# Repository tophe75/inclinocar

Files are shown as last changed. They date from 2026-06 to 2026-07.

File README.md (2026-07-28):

# InclinoCar

Rooftop tent leveling assistant. Runs on three hardware targets (ESP32-C3 + MPU-6050, M5StickC Plus, or M5StickS3), displays real-time pitch and roll on-device, and connects to the InclinoCar Android app via Bluetooth.

## Web Installer

Flash firmware directly in your browser — no drivers or software needed.

> ⚠️ Flash the device **before** assembling it into the case — the original case has no access hole for the BOOT button once assembled.

👉 **[tophe75.github.io/inclinocar](https://tophe75.github.io/inclinocar/)**

Requires Chrome or Edge on desktop.

---

## Latest Releases

🔧 **Firmware:**
- ESP32-C3 Super Mini 
- M5StickC Plus 
- M5StickS3 

🤖 **Android:** 

🍎 **iOS:** 

---

## Hardware

InclinoCar runs on three hardware targets. The ESP32-C3 is the DIY option; the two M5Stack sticks are all-in-one units with built-in display, IMU, and battery.

### Option 1 — ESP32-C3 Super Mini (DIY)

- [ESP32-C3 Super Mini](https://www.amazon.com/DWEII-ESP32-C3-Development-Supermini-Bluetooth/dp/B0G5XS345R)
- [SSD1306 OLED display 128×64 (I2C)](https://www.amazon.com/UCTRONICS-SSD1306-Self-Luminous-Display-Raspberry/dp/B072Q2X2LL)
- [MPU-6050 GY-521 accelerometer/gyroscope](https://www.amazon.com/EPLZON-MPU-6050-Accelerometer-Gyroscope-Converter/dp/B09TVYVC6X)
- [Momentary push button](https://www.amazon.com/Gebildet-Momentary-Button-Switch-Railway/dp/B07YDHP3HS)
- [Jumper wires (26 AWG Silicone)](https://www.amazon.com/Fermerry-Stranded-Colors-Flexible-electrical/dp/B089D3T1JD)

### Option 2 — M5StickC Plus

All-in-one unit with built-in MPU6886 IMU, colour display and battery. No wiring needed. The MPU6886 can drift and is a little noisy — acceptable for leveling but not the best of the three.

[M5StickC Plus](https://shop.m5stack.com/products/m5stickc-plus-esp32-pico-mini-iot-development-kit)

### Option 3 — M5StickS3 (recommended all-in-one)

All-in-one unit with the newer BMI270 IMU — noticeably more stable than the MPU6886 — plus a larger 250mAh battery.

[M5StickS3](https://shop.m5stack.com/products/m5sticks3-esp32s3-mini-iot-dev-kit)

> ℹ️ The M5StickS3 can **freeze (not reboot)** when connected to a PC via USB with no application actively reading the serial port — e.g. developing with VS Code/PlatformIO open but no serial monitor attached. It stays frozen on whatever it last displayed; opening a serial monitor un-freezes it immediately, closing the monitor again re-freezes it. This only affects that specific dev-workflow scenario — it does not happen through the [Web Installer](https://tophe75.github.io/inclinocar/) (its console actively reads the output), and normal use (battery, USB charger, power bank, car USB, or connected only to the phone app) is unaffected.

### Wiring (ESP32-C3 only)

All devices share the same I2C bus on GPIO6 and GPIO7.

```
ESP32-C3          SSD1306 OLED
─────────         ────────────
3.3V      →       VCC
GND       →       GND
GPIO6     →       SDA
GPIO7     →       SCL

ESP32-C3          MPU-6050 GY-521
─────────         ───────────────
3.3V      →       VCC
GND       →       GND
GPIO6     →       SDA
GPIO7     →       SCL
GND       →       AD0        (sets I2C address to 0x68)

ESP32-C3          Button
─────────         ──────
GPIO5     →       Terminal 1
GND       →       Terminal 2
(internal pull-up — no resistor needed)
```

The M5StickC Plus and M5StickS3 need no wiring — display, IMU, button and battery are all built in.

---

## Installation

1. Open the [Web Installer](https://tophe75.github.io/inclinocar/) in Chrome or Edge
2. Select your hardware (ESP32-C3, M5StickC Plus, or M5StickS3)
3. Select the firmware version
4. Click **Install**
5. Select **Erase device** when prompted — required for first install
6. Device reboots automatically when done

For the M5 sticks, hold the power button ~2 seconds to enter download mode if the installer can't connect.

---

## Usage

### Boot Screen

On power-up the device shows the device nickname, firmware version, MAC address and PIN for 5 seconds:

```
  InclinoCore
  v26.07.2
  E8:3D:C1:9E:43:38
  PIN: 9208
  Cal loaded
```

You can redisplay this screen at any time for 10 seconds — handy for reading the pairing PIN without power-cycling the device (see **Button** below).

### Display

```
  InclinoCore        PIN:9208
  ──────────────────────────
  P  +2.3°
  R  -1.1°
  ──────────────────────────
  Adjust...            ← or ** LEVEL ** when within 1°
```

`BT` appears in the top right when the app is connected. The M5 sticks also show battery percentage.

### Button

| Action | Function |
|---|---|
| Short press | Cycle display brightness (25% → 50% → 75% → 100% → 25%) |
| Hold 1 second | Calibrate (keep device still on flat ground) |
| Show boot screen for 10s | Redisplay nickname, MAC, and PIN — see device-specific gesture below |

- **ESP32-C3**: the wired push button. Short press / hold 1s as above. **Double-press** (two clicks within 350ms) shows the boot screen — this adds a ~350ms delay before short-press brightness cycling fires, needed to tell a single click from the first half of a double-click.
- **M5StickC Plus / M5StickS3**: `BtnA`, the front button (same side as the display — labeled **M5** on the M5StickC Plus; unlabeled but colored blue on the M5StickS3), for short press / hold 1s as above. `BtnB`, the top button, shows the boot screen with a single press. The bottom power button is unrelated to these functions.

Default brightness on first boot is 25%.

### Calibration

Hold the button (`BtnA` on the M5 sticks) for 1 second with the vehicle on flat level ground. The device takes 50 readings and saves the offsets to flash — they survive reboots and firmware updates.

### Bluetooth Pairing

1. Open the InclinoCar app
2. Tap the **⋮** menu → **Scan for InclinoCore**
3. Select your device from the list (identified by MAC address)
4. Enter the 4-digit PIN shown on the device display
5. The app remembers your device and auto-connects next time

The PIN is unique to each device and never changes.

### Bluetooth Data

The device sends JSON over Nordic UART Service (NUS) every 100ms:

```json
{"p":1.2,"r":0.3,"n":"InclinoCore"}
```

`p` = pitch (degrees), `r` = roll (degrees), `n` = device nickname

---

## Troubleshooting

| Problem | Solution |
|---|---|
| Display blank after flash (ESP32-C3) | Check SDA=GPIO6, SCL=GPIO7, VCC=3.3V |
| IMU not found (ESP32-C3) | Check MPU-6050 wiring, AD0 must be GND |
| M5 stick won't flash | Hold power button ~2s to enter download mode |
| M5StickS3 freezes when connected to PC (VS Code open, no serial monitor) | Normal — open a serial monitor to un-freeze it, or run on battery/charger/power bank instead. Only affects USB dev workflows, not normal use or the Web Installer. |
| Values drifting | Hold button 1s to calibrate |
| App can't find device | Menu → Scan for InclinoCore, check device is powered on |
| Wrong PIN | Check the device display — PIN is shown on boot screen and top-right when not connected |
| Web installer fails | Hard refresh (Ctrl+Shift+R) or use incognito window |
| NVS errors in serial log | Flash with Erase device selected in web installer |

---

## Android App

Download the latest `InclinoCar-installer.apk` from [GitHub Releases](https://github.com/tophe75/inclinocar/releases).

**Install instructions:**
1. Download the APK on your Android phone
2. Settings → Security → Install unknown apps → allow your browser
3. Open the APK and tap Install

**Features:**
- Auto-connects to last known device on startup
- PIN-based pairing for identifying your device among multiple units
- Bubble level with car silhouette and directional arrows
- Pitch and roll readout with colour coding (green < 1°, amber < 3°, red ≥ 3°)
- Calibrate remotely from the app
- Set a custom nickname for your device
- Known devices list with ability to remove saved devices
- Screen-on mode to keep display active while leveling

---

## 3D Printed Parts

STL files for cases and mounting brackets are in the `3d-print/` folder. Print in PETG or ABS — avoid PLA as it can warp in a hot car.

---

## Project Structure

```
firmware/
  firmware-esp32c3/   PlatformIO project (ESP32-C3 + MPU-6050 + SSD1306)
  firmware-m5stick/   PlatformIO project (M5StickC Plus)
  firmware-m5sticks3/ PlatformIO project (M5StickS3)
app/                  Flutter app (Android + iOS)
  app/lib/            Dart source code
  app/android/        Android build files and icons
  app/ios/            iOS build files and icons
  app/assets/         App assets (master icon, Play Store icon)
docs/                 GitHub Pages web installer
3d-print/             STL files for cases and mounting brackets
scripts/              Build utilities (version injection)
.github/workflows/    CI/CD pipelines
```

## Building Locally

**Firmware** — requires [VS Code](https://code.visualstudio.com/) and [PlatformIO](https://platformio.org/install/ide?install=vscode).
Open the relevant `firmware/firmware-*` folder in VS Code and click **Upload**.

**App** — requires [Flutter](https://flutter.dev/docs/get-started/install) SDK.
```bash
cd app
flutter pub get
flutter build apk --release
```

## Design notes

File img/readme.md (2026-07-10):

inclinocar_andriod_app_screenshoot

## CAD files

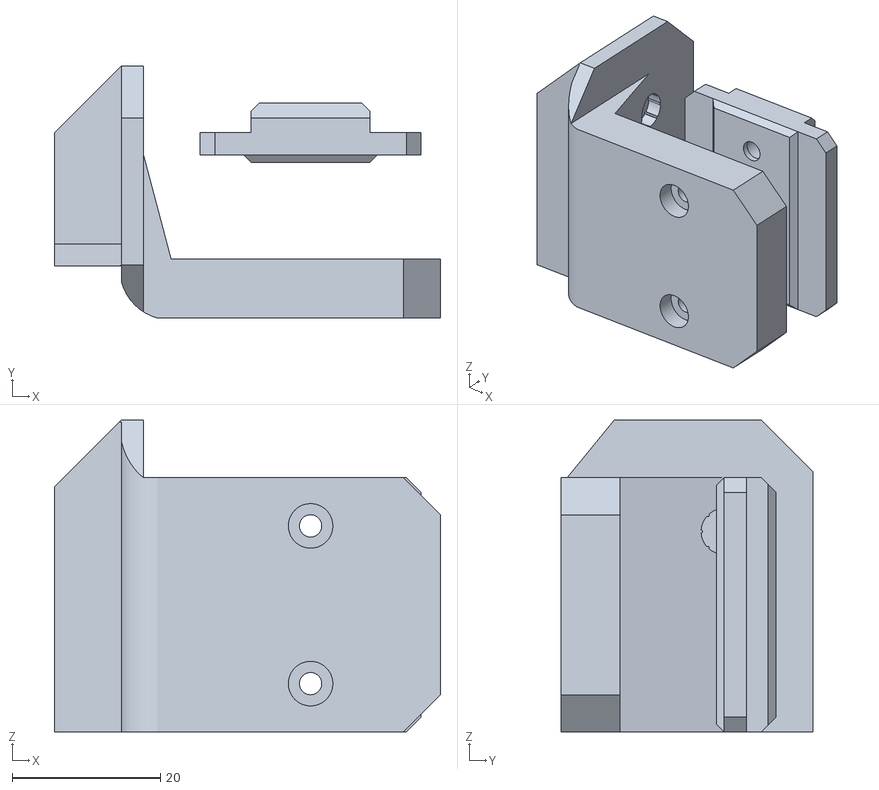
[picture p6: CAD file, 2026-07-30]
3d-print/brackets/Taktältarna_Åreskutan_2.0/InclinoCar M5S3 v26.07.1 - Bracket_TT_Åreskutan2.0.stl
52.0 x 34.0 x 42.0

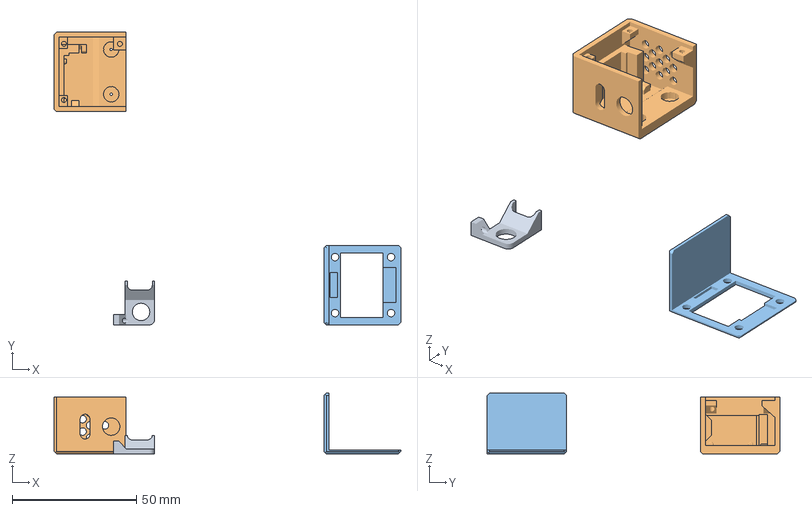
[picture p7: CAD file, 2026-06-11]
3d-print/core/esp32-c3_supermini/InclinoCar Core Case.3mf
139.5 x 117.7 x 24.5 mm
InclinoCar Core Case v26.1.0 - Clip.stl
InclinoCar Core Case v26.1.0 - Box.stl
InclinoCar Core Case v26.1.0 - Lid.stl

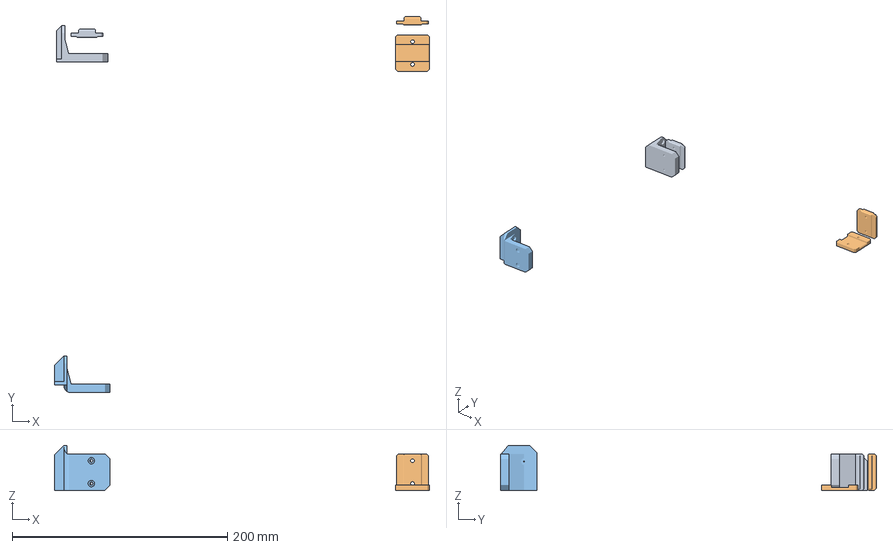
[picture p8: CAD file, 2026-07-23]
3d-print/brackets/Taktältarna_Åreskutan_2.0/InclinoCar - TT Brackets.3mf
349.2 x 349.7 x 42.0 mm
InclinoCar Core Case v26.1.0 - Bracket_TT_Åreskutan2.0.stl
InclinoCar Core Case v26.1.0 - Powerbank_TT_Åreskutan2.0.stl
InclinoCar M5S3 v26.07.1 - Bracket_TT_Åreskutan2.0.stl

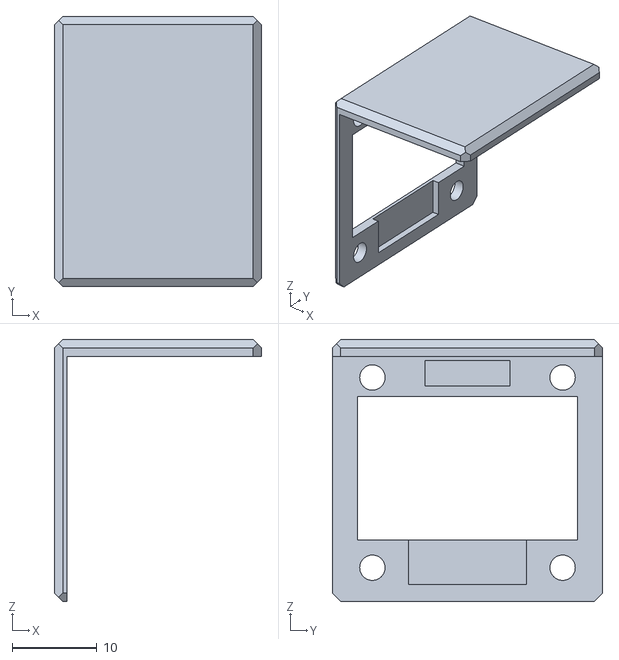
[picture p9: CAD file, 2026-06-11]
3d-print/core/esp32-c3_supermini/InclinoCar Core Case v26.1.0 - Lid.stl
24.5 x 32.0 x 31.0

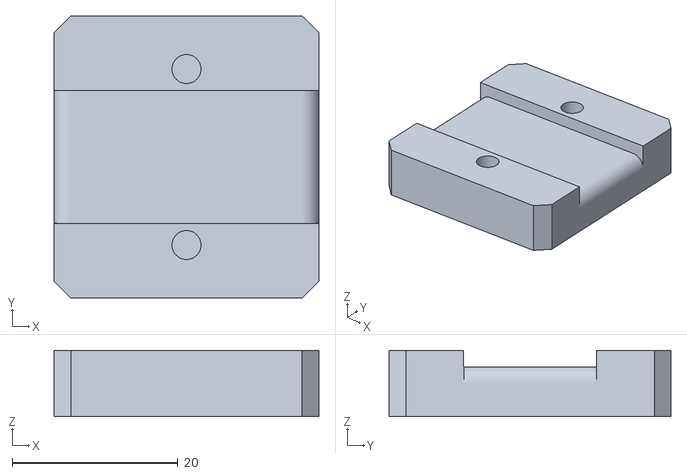
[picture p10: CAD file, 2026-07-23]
3d-print/brackets/Taktältarna_Åreskutan_2.0/InclinoCar Core Case v26.1.1 - Powerbank_TT_Åreskutan2.0.stl
32.0 x 34.0 x 8.00

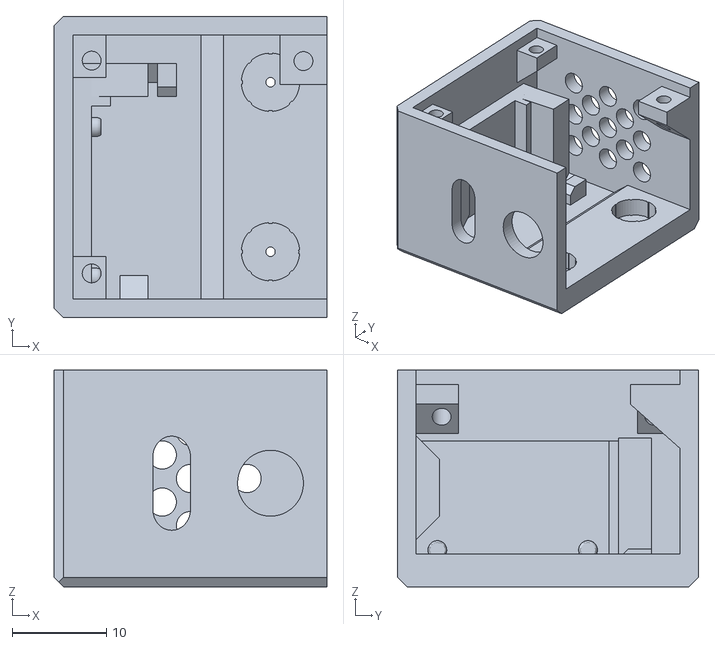
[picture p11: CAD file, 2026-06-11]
3d-print/core/esp32-c3_supermini/InclinoCar Core Case v26.1.0 - Box.stl
29.0 x 32.0 x 23.0

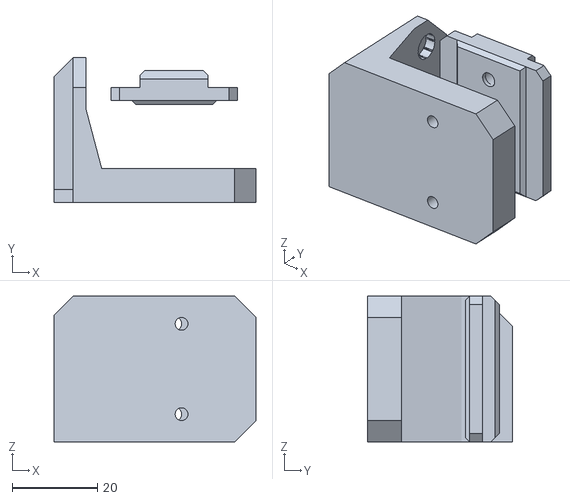
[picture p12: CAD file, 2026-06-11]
3d-print/brackets/Taktältarna_Åreskutan_2.0/InclinoCar Core Case v26.1.0 - Bracket_TT_Åreskutan2.0.stl
47.5 x 34.0 x 34.2

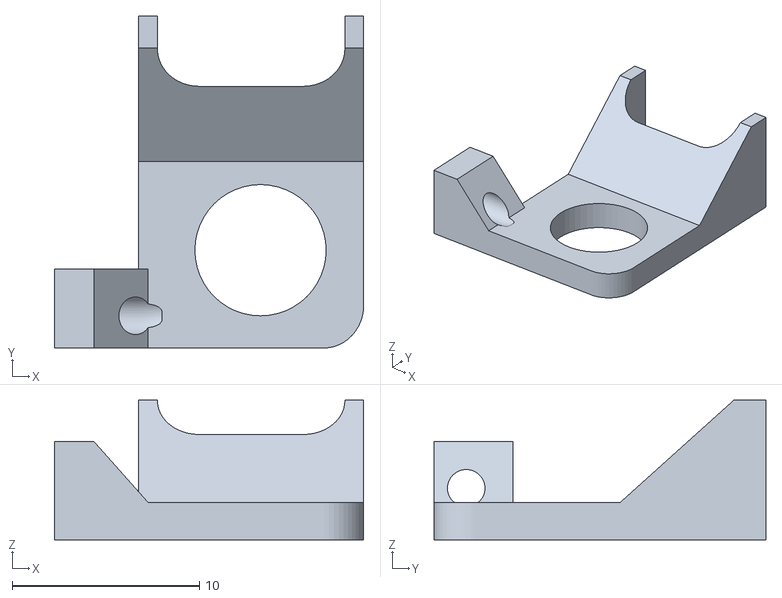
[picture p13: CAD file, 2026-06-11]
3d-print/core/esp32-c3_supermini/InclinoCar Core Case v26.1.0 - Clip.stl
16.5 x 17.7 x 7.45

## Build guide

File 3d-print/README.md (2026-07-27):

# 3D Print Files

This folder contains STL files for 3D printed parts.

InclinoCore_left
InclinoCore_all_explode

## Parts

| Folder | File | Description | Status |
|---|---|---|---|
| `core/esp32-c3_supermini/` | Core Case v26.1.0 (Box/Clip/Lid + .3mf) | ESP32-C3 Super Mini + OLED case | Published |
| `brackets/Taktältarna_Åreskutan_2.0/` | TT Brackets.3mf | Tent bar mounting bracket (project file) | Published |
| `brackets/Taktältarna_Åreskutan_2.0/` | Core Case v26.1.0 - Bracket | Case variant for Taktältarna Åreskutan 2.0 bracket mount | Published |
| `brackets/Taktältarna_Åreskutan_2.0/` | Core Case v26.1.1 - Powerbank | Case variant for Taktältarna Åreskutan 2.0, with power bank | Published |
| `brackets/Taktältarna_Åreskutan_2.0/` | M5S3 v26.07.1 - Bracket | M5StickS3 mount for Taktältarna Åreskutan 2.0 bracket | Published |

## Print Settings

Recommended settings for all parts:

- **Material:**  PLA should be fine as this is only mounted during leveling, if you plan to store the device in a hot car consider PETG
- **Infill:** 15%
- **Layer height:** 0.2mm
- **Supports:** not needed in the current version
- **Walls:** 2 (top/bottom 3)

## Notes

- PETG is preferred over PLA for in-car use — PLA can warp in a hot car
- Core uses M2x4mm screws
- For brackets parts use M3 heat-set inserts

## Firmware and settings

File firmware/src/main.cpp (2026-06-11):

#include <Arduino.h>
#include <Wire.h>
#include <Preferences.h>
#include <Adafruit_MPU6050.h>
#include <Adafruit_Sensor.h>
#include <Adafruit_SSD1306.h>
#include <math.h>
#include <NimBLEDevice.h>
#include <esp_mac.h>

// I2C: SDA=GPIO6, SCL=GPIO7
// Button: GPIO5 → GND (hold 1s = calibrate)
#define SDA_PIN       6
#define SCL_PIN       7
#define BTN_PIN       5
#define CAL_HOLD_MS   1000

// Nordic UART Service UUIDs
#define NUS_SERVICE_UUID  "6E400001-B5A3-F393-E0A9-E50E24DCCA9E"
#define NUS_RX_UUID       "6E400002-B5A3-F393-E0A9-E50E24DCCA9E"  // phone → device
#define NUS_TX_UUID       "6E400003-B5A3-F393-E0A9-E50E24DCCA9E"  // device → phone

// Device nickname (user settable)
char deviceNickname[32] = "InclinoCore";
char bleAdvName[32]    = "InclinoCore";  // BLE advertising name — Core#MAC, never changes
uint16_t devicePIN = 0;

void generateBleAdvName() {
  uint8_t mac[6];
  esp_read_mac(mac, ESP_MAC_WIFI_STA);
  snprintf(bleAdvName, sizeof(bleAdvName), "Core#%02X%02X%02X%02X%02X%02X",
    mac[0], mac[1], mac[2], mac[3], mac[4], mac[5]);
}

uint16_t generatePIN() {
  // Deterministic PIN from MAC — same device always same PIN
  uint8_t mac[6];
  esp_read_mac(mac, ESP_MAC_WIFI_STA);
  return (mac[4] * 256 + mac[5]) % 9000 + 1000;
}

Adafruit_SSD1306 display(128, 64, &Wire, -1);
Adafruit_MPU6050 mpu;
Preferences prefs;

float pitchOffset    = 0.0;
float rollOffset     = 0.0;
float smoothedPitch  = 0.0;
float smoothedRoll   = 0.0;
const float ALPHA    = 0.15f;  // lower = smoother, higher = more responsive

// Brightness levels: 25%, 50%, 75%, 100%
const uint8_t BRIGHTNESS_LEVELS[] = {64, 128, 192, 255};
const int     BRIGHTNESS_COUNT     = 4;
int           brightnessIndex      = 0;  // default 25%

// Brightness levels 0-3 → 64, 128, 192, 255

bool          btnWasPressed    = false;
unsigned long btnPressTime      = 0;
bool          calibratePending  = false;
bool          pinVerified       = false;

// BLE
NimBLEServer*         pServer  = nullptr;
NimBLECharacteristic* pTxChar  = nullptr;
bool bleConnected = false;

class ServerCallbacks : public NimBLEServerCallbacks {
  void onConnect(NimBLEServer* s) override {
    bleConnected = true;
    Serial.println("BLE connected");
  }
  void onDisconnect(NimBLEServer* s) override {
    bleConnected = false;
    pinVerified  = false;
    Serial.println("BLE disconnected");
    NimBLEDevice::startAdvertising();
  }
};

void saveNickname();  // forward declaration

class RxCallbacks : public NimBLECharacteristicCallbacks {
  void onWrite(NimBLECharacteristic* c) override {
    std::string val = c->getValue();
    String cmd = String(val.c_str());
    cmd.trim();
    Serial.printf("BLE RX: %s\n", cmd.c_str());
    if (cmd.startsWith("KNOWNMAC:")) {
      // Known device reconnecting — skip PIN
      pinVerified = true;
      Serial.println("BLE: known device reconnected");
      if (pTxChar) {
        String ack = "{\"pin\":\"ok\",\"n\":\"" + String(deviceNickname) + "\"}\n";
        pTxChar->setValue((uint8_t*)ack.c_str(), ack.length());
        pTxChar->notify();
      }
    } else if (cmd.startsWith("PIN:")) {
      uint16_t entered = cmd.substring(4).toInt();
      if (entered == devicePIN) {
        pinVerified = true;
        Serial.println("BLE: PIN verified");
        // Send confirmation
        if (pTxChar) {
          String ack = String("{\"pin\":\"ok\",\"n\":\"") + deviceNickname + "\"}\n";
          pTxChar->setValue((uint8_t*)ack.c_str(), ack.length());
          pTxChar->notify();
        }
      } else {
        Serial.println("BLE: PIN rejected");
        if (pTxChar) {
          String nak = "{\"pin\":\"fail\"}\n";
          pTxChar->setValue((uint8_t*)nak.c_str(), nak.length());
          pTxChar->notify();
        }
      }
    } else if (cmd == "CAL") {
      if (pinVerified) calibratePending = true;
      Serial.println("BLE: calibration requested");
    } else if (cmd.startsWith("NICK:")) {
      String nick = cmd.substring(5);
      nick.trim();
      if (nick.length() > 0 && nick.length() < 32) {
        nick.toCharArray(deviceNickname, sizeof(deviceNickname));
        saveNickname();
        Serial.printf("BLE: nickname set to %s\n", deviceNickname);
      }
    }
  }
};

void setupBLE() {
  NimBLEDevice::init(bleAdvName);
  pServer = NimBLEDevice::createServer();
  pServer->setCallbacks(new ServerCallbacks());

  NimBLEService* pService = pServer->createService(NUS_SERVICE_UUID);

  // TX characteristic — device sends data to phone
  pTxChar = pService->createCharacteristic(
    NUS_TX_UUID,
    NIMBLE_PROPERTY::NOTIFY
  );

  // RX characteristic — phone sends commands to device
  auto* pRxChar = pService->createCharacteristic(
    NUS_RX_UUID,
    NIMBLE_PROPERTY::READ | NIMBLE_PROPERTY::WRITE | NIMBLE_PROPERTY::WRITE_NR
  );
  pRxChar->setCallbacks(new RxCallbacks());

  pService->start();

  NimBLEAdvertising* pAdv = NimBLEDevice::getAdvertising();
  pAdv->addServiceUUID(NUS_SERVICE_UUID);
  pAdv->setScanResponse(true);
  NimBLEDevice::startAdvertising();
  Serial.printf("BLE advertising as '%s' nickname='%s'\n", bleAdvName, deviceNickname);
}

void saveBrightness() {
  prefs.begin("inclinocar", false);
  prefs.putInt("brightness", brightnessIndex);
  prefs.end();
}

void saveNickname() {
  prefs.begin("inclinocar", false);
  prefs.putString("nickname", deviceNickname);
  prefs.end();
  // Update BLE advertising name and restart advertising
  // BLE advertising name stays as bleAdvName — nickname is display only
}

void loadNickname() {
  prefs.begin("inclinocar", true);
  String saved = prefs.getString("nickname", "InclinoCore");
  prefs.end();
  saved.toCharArray(deviceNickname, sizeof(deviceNickname));
  Serial.printf("Nickname: %s\n", deviceNickname);
}

void saveOffsets() {
  prefs.begin("inclinocar", false);
  prefs.putFloat("pitchOff", pitchOffset);
  prefs.putFloat("rollOff",  rollOffset);
  prefs.end();
}


void applyBrightness() {
  display.ssd1306_command(SSD1306_SETCONTRAST);
  display.ssd1306_command(BRIGHTNESS_LEVELS[brightnessIndex]);
}

void loadBrightness() {
  prefs.begin("inclinocar", true);
  brightnessIndex = prefs.getInt("brightness", 0);  // default 25%
  prefs.end();
  Serial.printf("Brightness loaded: index=%d val=%d\n", brightnessIndex, BRIGHTNESS_LEVELS[brightnessIndex]);
}

void loadOffsets() {
  prefs.begin("inclinocar", true);
  pitchOffset     = prefs.getFloat("pitchOff", 0.0);
  rollOffset      = prefs.getFloat("rollOff",  0.0);
  brightnessIndex = prefs.getInt("brightness", 0);  // default 25%
  prefs.end();
  Serial.printf("Offsets loaded: pitch=%.2f roll=%.2f brightness=%d\n", pitchOffset, rollOffset, brightnessIndex);
}


void cycleBrightness() {
  brightnessIndex = (brightnessIndex + 1) % BRIGHTNESS_COUNT;
  applyBrightness();
  saveBrightness();

  // Brief feedback on screen
  display.clearDisplay();
  display.setTextColor(SSD1306_WHITE);
  display.setTextSize(1);
  display.setCursor(0, 20);
  display.println("  Brightness:");
  display.setTextSize(2);
  display.setCursor(20, 36);
  int pct = (BRIGHTNESS_LEVELS[brightnessIndex] * 100) / 255;
  display.printf("  %d%%", pct);
  display.display();
  delay(800);
}

void calibrate() {
  display.clearDisplay();
  display.setTextColor(SSD1306_WHITE);
  display.setTextSize(1);
  display.setCursor(0, 0);  display.println("  Calibrating...");
  display.setCursor(0, 16); display.println("  Keep still!");
  display.display();
  delay(500);

  float pSum = 0, rSum = 0;
  for (int i = 0; i < 50; i++) {
    sensors_event_t a, g, t;
    mpu.getEvent(&a, &g, &t);
    float rp = atan2(-a.acceleration.x,
                  sqrt(a.acceleration.y*a.acceleration.y +
                       a.acceleration.z*a.acceleration.z)) * 180.0/PI;
    float rr = atan2(a.acceleration.y, a.acceleration.z) * 180.0/PI;
    // Apply same CW 90 rotation
    pSum +=  rr;
    rSum +=  rp;
    delay(20);
  }
  pitchOffset = pSum / 50.0;
  rollOffset  = rSum / 50.0;
  saveOffsets();

  display.clearDisplay();
  display.setCursor(0, 0);  display.println("  Cal saved!");
  display.setCursor(0, 16); display.printf("  P: %.1f\n", pitchOffset);
  display.setCursor(0, 28); display.printf("  R: %.1f\n", rollOffset);
  display.display();
  delay(5000);
}

void showBrightnessMsg() {
  display.clearDisplay();
  display.setTextColor(SSD1306_WHITE);
  display.setTextSize(1);
  display.setCursor(0, 20); display.println("  Brightness:");
  display.setTextSize(2);
  int pct = (brightnessIndex + 1) * 25;
  display.setCursor(32, 36); display.printf("%d%%", pct);
  display.display();
  delay(600);
}

void handleButton() {
  bool pressed = (digitalRead(BTN_PIN) == LOW);

  if (pressed && !btnWasPressed) {
    btnPressTime  = millis();
    btnWasPressed = true;
  }

  // Released before hold threshold — single press → brightness
  if (!pressed && btnWasPressed) {
    btnWasPressed = false;
    unsigned long held = millis() - btnPressTime;
    if (held < CAL_HOLD_MS) {
      cycleBrightness();
    }
  }

  // Still held past threshold → calibrate
  if (pressed && btnWasPressed && millis() - btnPressTime >= CAL_HOLD_MS) {
    btnWasPressed = false;
    calibrate();
  }
}

void setup() {
  Serial.begin(115200);
  pinMode(BTN_PIN, INPUT_PULLUP);

  Wire.begin(SDA_PIN, SCL_PIN);

  if (!display.begin(SSD1306_SWITCHCAPVCC, 0x3C)) {
    Serial.println("OLED failed"); while(1);
  }

  display.clearDisplay();
  display.setTextColor(SSD1306_WHITE);
  display.setTextSize(1);
  display.setCursor(0, 0);  display.println(deviceNickname);
  display.setCursor(0, 12); display.println("  " FW_VERSION);
  display.setCursor(0, 28); display.println("  Starting...");
  display.display();

  if (!mpu.begin()) {
    display.setCursor(0, 44); display.println("  IMU not found!");
    display.display();
    Serial.println("MPU-6050 failed"); while(1);
  }
  mpu.setAccelerometerRange(MPU6050_RANGE_8_G);
  mpu.setFilterBandwidth(MPU6050_BAND_21_HZ);

  loadOffsets();
  loadNickname();
  loadBrightness();
  generateBleAdvName();
  devicePIN = generatePIN();
  Serial.printf("Device PIN: %04d\n", devicePIN);
  applyBrightness();
  setupBLE();

  display.clearDisplay();
  // Show MAC and PIN on boot screen
  uint8_t mac[6];
  esp_read_mac(mac, ESP_MAC_WIFI_STA);
  char macStr[18];
  snprintf(macStr, sizeof(macStr), "%02X:%02X:%02X:%02X:%02X:%02X",
    mac[0],mac[1],mac[2],mac[3],mac[4],mac[5]);
  display.setCursor(0, 0);  display.println(deviceNickname);
  display.setCursor(0, 12); display.println("  " FW_VERSION);
  display.setCursor(0, 26); display.printf("  %s", macStr);
  display.setCursor(0, 40); display.printf("  PIN: %04d", devicePIN);
  display.setCursor(0, 54); display.println(
    (pitchOffset != 0.0 || rollOffset != 0.0) ? "  Cal loaded" : "  Hold btn: cal");
  display.display();
  delay(5000);
}

void loop() {
  handleButton();

  if (calibratePending) {
    calibratePending = false;
    calibrate();
  }

  sensors_event_t a, g, temp;
  mpu.getEvent(&a, &g, &temp);

  // Raw axis values (no offset yet)
  float rawPitch = atan2(-a.acceleration.x,
                   sqrt(a.acceleration.y*a.acceleration.y +
                        a.acceleration.z*a.acceleration.z)) * 180.0/PI;
  float rawRoll  = atan2(a.acceleration.y, a.acceleration.z) * 180.0/PI;

  // Rotate axes CW 90 degrees then apply calibration offsets
  float rotPitch =  rawRoll  - pitchOffset;
  float rotRoll  =  rawPitch - rollOffset;

  // Exponential moving average to reduce jitter
  smoothedPitch = ALPHA * rotPitch + (1.0f - ALPHA) * smoothedPitch;
  smoothedRoll  = ALPHA * rotRoll  + (1.0f - ALPHA) * smoothedRoll;

  float pitch = smoothedPitch;
  float roll  = smoothedRoll;

  // Send JSON over BLE NUS — only after PIN verified
  if (bleConnected && pinVerified) {
    char buf[96];
    snprintf(buf, sizeof(buf), "{\"p\":%.1f,\"r\":%.1f,\"n\":\"%s\"}\n", pitch, roll, deviceNickname);
    pTxChar->setValue((uint8_t*)buf, strlen(buf));
    pTxChar->notify();
  }

  Serial.printf("P:%+6.1f  R:%+6.1f  BLE:%s\n", pitch, roll, bleConnected ? "connected" : "advertising");

  // Update display
  display.clearDisplay();
  display.setTextSize(1);
  display.setTextColor(SSD1306_WHITE);
  // Left: "InclinoCar vX.X.X"  Right: "BT+" — drawn separately so they never overlap
  display.setCursor(0, 0);
  display.print(deviceNickname);
  display.drawLine(0, 10, 127, 10, SSD1306_WHITE);

  display.setTextSize(2);
  display.setCursor(0, 16);
  display.printf("P%6.1f", pitch);
  display.setTextSize(1); display.print((char)247);

  display.setTextSize(2);
  display.setCursor(0, 38);
  display.printf("R%6.1f", roll);
  display.setTextSize(1); display.print((char)247);

  display.drawLine(0, 54, 127, 54, SSD1306_WHITE);
  display.setCursor(0, 57);
  display.setTextSize(1);
  bool level = abs(pitch) < 1.0 && abs(roll) < 1.0;
  display.print(level ? "  ** LEVEL **" : "  Adjust...");

  // Show PIN when not connected so user can always find it
  if (bleConnected && pinVerified) {
    display.setCursor(116, 0);
    display.print("BT");
  } else if (!bleConnected) {
    display.setCursor(68, 0);
    display.printf("PIN:%04d", devicePIN);
  }

  display.display();
  delay(100);
}

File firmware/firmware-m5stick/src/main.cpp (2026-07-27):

#include <Arduino.h>
#include <M5Unified.h>
#include <Preferences.h>
#include <NimBLEDevice.h>
#include <esp_mac.h>
#include <math.h>

#define CAL_HOLD_MS 1000

#define NUS_SERVICE_UUID  "6E400001-B5A3-F393-E0A9-E50E24DCCA9E"
#define NUS_RX_UUID       "6E400002-B5A3-F393-E0A9-E50E24DCCA9E"
#define NUS_TX_UUID       "6E400003-B5A3-F393-E0A9-E50E24DCCA9E"

#define C_BG    TFT_BLACK
#define C_GREEN 0x07E0
#define C_AMBER 0xFD20
#define C_WHITE TFT_WHITE
#define C_DIM   0x4208
#define C_RED   TFT_RED

char     deviceNickname[32] = "InclinoCore";
char     bleAdvName[32]     = "InclinoCore";
uint16_t devicePIN          = 0;

void generateBleAdvName() {
  uint8_t mac[6];
  esp_read_mac(mac, ESP_MAC_WIFI_STA);
  snprintf(bleAdvName, sizeof(bleAdvName), "Core#%02X%02X%02X%02X%02X%02X",
    mac[0], mac[1], mac[2], mac[3], mac[4], mac[5]);
}

uint16_t generatePIN() {
  uint8_t mac[6];
  esp_read_mac(mac, ESP_MAC_WIFI_STA);
  return (mac[4] * 256 + mac[5]) % 9000 + 1000;
}

Preferences prefs;

float pitchOffset   = 0.0;
float rollOffset    = 0.0;
// Median filter — 5 samples, eliminates spikes without lag
#define MF_SIZE 7
float pitchBuf[MF_SIZE] = {0};
float rollBuf[MF_SIZE]  = {0};
int   mfIndex = 0;
bool  mfFull  = false;

float medianOf5(float* buf) {
  float tmp[MF_SIZE];
  memcpy(tmp, buf, sizeof(tmp));
  // Simple sort
  for (int i = 0; i < MF_SIZE-1; i++)
    for (int j = i+1; j < MF_SIZE; j++)
      if (tmp[j] < tmp[i]) { float t=tmp[i]; tmp[i]=tmp[j]; tmp[j]=t; }
  return tmp[MF_SIZE/2];
}

const uint8_t BRIGHTNESS_LEVELS[] = {64, 128, 192, 255};
const int     BRIGHTNESS_COUNT    = 4;
int           brightnessIndex     = 0;

bool          btnWasPressed    = false;
unsigned long btnPressTime     = 0;
bool          calibratePending = false;
bool          pinVerified      = false;

NimBLEServer*         pServer = nullptr;
NimBLECharacteristic* pTxChar = nullptr;
bool bleConnected = false;

class ServerCallbacks : public NimBLEServerCallbacks {
  void onConnect(NimBLEServer* s) override {
    bleConnected = true;
    Serial.println("BLE connected");
  }
  void onDisconnect(NimBLEServer* s) override {
    bleConnected = false;
    pinVerified  = false;
    Serial.println("BLE disconnected");
    NimBLEDevice::startAdvertising();
  }
};

void saveNickname();

class RxCallbacks : public NimBLECharacteristicCallbacks {
  void onWrite(NimBLECharacteristic* c) override {
    std::string val = c->getValue();
    String cmd = String(val.c_str());
    cmd.trim();
    Serial.printf("BLE RX: %s\n", cmd.c_str());
    if (cmd.startsWith("KNOWNMAC:")) {
      pinVerified = true;
      if (pTxChar) {
        String ack = "{\"pin\":\"ok\",\"n\":\"" + String(deviceNickname) + "\"}\n";
        pTxChar->setValue((uint8_t*)ack.c_str(), ack.length());
        pTxChar->notify();
      }
    } else if (cmd.startsWith("PIN:")) {
      uint16_t entered = cmd.substring(4).toInt();
      if (entered == devicePIN) {
        pinVerified = true;
        if (pTxChar) {
          String ack = String("{\"pin\":\"ok\",\"n\":\"") + deviceNickname + "\"}\n";
          pTxChar->setValue((uint8_t*)ack.c_str(), ack.length());
          pTxChar->notify();
        }
      } else {
        if (pTxChar) {
          String nak = "{\"pin\":\"fail\"}\n";
          pTxChar->setValue((uint8_t*)nak.c_str(), nak.length());
          pTxChar->notify();
        }
      }
    } else if (cmd == "CAL") {
      if (pinVerified) calibratePending = true;
    } else if (cmd.startsWith("NICK:")) {
      String nick = cmd.substring(5);
      nick.trim();
      if (nick.length() > 0 && nick.length() < 32) {
        nick.toCharArray(deviceNickname, sizeof(deviceNickname));
        saveNickname();
      }
    }
  }
};

void setupBLE() {
  NimBLEDevice::init(bleAdvName);
  pServer = NimBLEDevice::createServer();
  pServer->setCallbacks(new ServerCallbacks());
  NimBLEService* pService = pServer->createService(NUS_SERVICE_UUID);
  pTxChar = pService->createCharacteristic(NUS_TX_UUID, NIMBLE_PROPERTY::NOTIFY);
  auto* pRxChar = pService->createCharacteristic(
    NUS_RX_UUID,
    NIMBLE_PROPERTY::READ | NIMBLE_PROPERTY::WRITE | NIMBLE_PROPERTY::WRITE_NR);
  pRxChar->setCallbacks(new RxCallbacks());
  pService->start();
  NimBLEAdvertising* pAdv = NimBLEDevice::getAdvertising();
  pAdv->addServiceUUID(NUS_SERVICE_UUID);
  pAdv->setScanResponse(true);
  NimBLEDevice::startAdvertising();
  Serial.printf("BLE advertising as '%s'\n", bleAdvName);
}

void saveNickname() {
  prefs.begin("inclinocar", false);
  prefs.putString("nickname", deviceNickname);
  prefs.end();
}

void loadNickname() {
  prefs.begin("inclinocar", true);
  String s = prefs.getString("nickname", "InclinoCore");
  prefs.end();
  s.toCharArray(deviceNickname, sizeof(deviceNickname));
}

void saveOffsets() {
  prefs.begin("inclinocar", false);
  prefs.putFloat("pitchOff", pitchOffset);
  prefs.putFloat("rollOff",  rollOffset);
  prefs.end();
}

void loadOffsets() {
  prefs.begin("inclinocar", true);
  pitchOffset     = prefs.getFloat("pitchOff", 0.0);
  rollOffset      = prefs.getFloat("rollOff",  0.0f);
  brightnessIndex = prefs.getInt("brightness", 0);
  prefs.end();
}

void applyBrightness() {
  M5.Display.setBrightness(BRIGHTNESS_LEVELS[brightnessIndex]);
}

void saveBrightness() {
  prefs.begin("inclinocar", false);
  prefs.putInt("brightness", brightnessIndex);
  prefs.end();
}

// Seed median filter with current accel reading
void seedFilters() {
  float ax, ay, az;
  M5.Imu.getAccelData(&ax, &ay, &az);
  float p = atan2(-ax, sqrt(ay*ay + az*az)) * 180.0/PI - pitchOffset;
  float r = atan2(ay, az) * 180.0/PI - 90.0f - rollOffset;
  for (int i = 0; i < MF_SIZE; i++) { pitchBuf[i] = p; rollBuf[i] = r; }
  mfIndex = 0;
  mfFull  = true;
  Serial.printf("Filter seeded: P=%.1f R=%.1f\n", p, r);
}
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

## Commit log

2026-05-28 Initial project scaffold — firmware, Flutter app, web installer
2026-05-29 v0.1.0 — Satellite is display-only, calibration button, ESP-NOW broadcast
2026-05-29 Fix CORS on binary download — use GitHub API asset endpoint
2026-05-29 Fix binary fetching — serve bins from docs/bins same-origin
2026-05-29 Fix esptool loading — use dynamic ES module import v0.6.0
2026-05-29 Fix esptool pako dependency — use esm.sh bundled import
2026-05-29 Fix port already open — let esptool manage serial port lifecycle
2026-05-29 Fix binary string conversion — use chunked fromCharCode
2026-05-29 Fix flash data format — pass Uint8Array directly to esptool-js
2026-05-29 Fix CI — add docs/libs to git commit so esptool bundle reaches Pages
2026-05-29 Fix post-flash reset — use loader.after instead of hardReset
2026-05-29 v0.1.6 — separate I2C buses, direct-solder OLED pins, boot screen, serial terminal
2026-05-29 v0.1.6 — separate I2C buses, boot screen, serial terminal, fix async syntax
2026-05-29 Add USE_OLED and USE_IMU build flags — enable boot screen and display
2026-05-29 Fix version display — inject git tag as FW_VERSION at build time
2026-05-31 Fix version injection using heredoc Python script, fix boot sequence
    [main.cpp]
2026-05-31 Fix version injection — move Python script to scripts/set_version.py
2026-05-31 Fix FW_VERSION: #ifndef fallback in config.h, correct escaping in set_version.py
    [main.cpp]
2026-05-31 v0.1.14 — clean rewrite core firmware, fix dual I2C, button, version
    [main.cpp]
2026-05-31 Fix set_version.py — inject FW_VERSION inside build_flags not after lib_deps
2026-05-31 Fix set_version.py — handle empty build_flags after FW_VERSION strip
2026-05-31 Fix I2C double-init — use Wire/Wire1 instead of custom TwoWire objects
    [main.cpp]
2026-05-31 Fix I2C init — use Wire.setPins() to avoid double-init with Adafruit libs
    [main.cpp]
2026-05-31 Fix OLED I2C init — dedicated TwoWire instance, skip internal Wire.begin
    [main.cpp]
2026-05-31 Clean slate — removing all files for rewrite
2026-05-31 Clean slate — remove all files and disable CI
2026-05-31 Fresh start — simple MPU6050 + OLED firmware, ESP Web Tools installer
2026-05-31 Fix workflow — Node.js 24, always create release on tag
2026-05-31 Fix OLED init — use Wire.setPins instead of Wire.begin
    [main.cpp]
2026-05-31 Fix I2C init, add version/firmware selectors to web installer
    [main.cpp]
2026-05-31 Fix CI push conflict — use force push for bin commits
2026-05-31 Remove IMU freeze, add debug output
2026-06-01 v0.0.8 — calibration button on GPIO5, single I2C bus GPIO6/7
2026-06-01 Fix installer — use local manifest.json not tag ref
2026-06-01 Fix manifest — remove trailing whitespace
2026-06-01 v0.0.9 — save calibration offsets to NVS, persist across reboots
    [main.cpp]
2026-06-01 v0.0.10 — satellite firmware, ESP-NOW pairing, dual build CI
2026-06-01 Fix ESP-NOW channel, NVS partition, pairing debug
    [main.cpp]
2026-06-01 Clean repo — remove VS Code and extra gitignore files
2026-06-01 Fix ESP-NOW rx — reset WiFi mode before STA to force clean radio state
    [main.cpp]
2026-06-01 Remove channel forcing — let ESP-NOW use default radio channel
2026-06-01 v0.1.0 — BLE Nordic UART Service, remove satellite/ESP-NOW, clean up
2026-06-01 Fix Gradle settings — read flutterRoot from local.properties
2026-06-01 Fix Gradle — bump Flutter to 3.24, pin flutter_blue_plus, compileSdk 35
2026-06-01 Fix BLE calibration — use pending flag instead of extern call
    [main.cpp]
2026-06-01 Fix calibrate button, add wake lock toggle
2026-06-01 Migrate to declarative Flutter Gradle plugin — fixes plugin compileSdk issue
2026-06-01 Replace wakelock_plus with native method channel — fixes build
2026-06-01 Fix Dart compile errors — initState and wakeLock in wrong classes
2026-06-01 Add 3D print folder, app version display, fix calibrate button, app icon setup
2026-06-01 Fix app icon, add calibrate debug logging, fix RX char discovery
    [main.cpp]
2026-06-01 Fix display header — left align version, right align BT indicator
    [main.cpp]
2026-06-01 Fix firmware workflow — remove paths filter so tag pushes always trigger build
2026-06-04 Rotate MPU axes CCW 90, add smoothing filter, clean up BT indicator
2026-06-04 Fix rotation CW, fix calibration offset applied after rotation
    [main.cpp]
2026-06-04 Swap pitch axis sign
    [main.cpp]
2026-06-04 Flip bubble level direction — negate pitch and roll
2026-06-04 v0.0.26 — single press cycles brightness, hold calibrates, brightness saved to NVS
2026-06-04 Fix duplicate definitions in brightness code
    [main.cpp]
2026-06-04 Fix all duplicate brightness declarations
    [main.cpp]
2026-06-04 v0.0.27 — InclinoCore rename, nickname, menu, confirm calibrate, auto-connect
2026-06-04 Fix forward declaration for saveNickname
    [main.cpp]
2026-06-04 v0.0.13 — Option D bubble level with car silhouette and directional arrows
2026-06-04 Fix pitch arrow direction
2026-06-05 Update README with flashing instructions
    Added a note about flashing the device before assembly.
2026-06-08 Web installer — serve older versions from GitHub Release assets
2026-06-08 Fix nickname not persisting — add loadNickname() to setup, use nickname for BLE init
    [main.cpp]
2026-06-08 Fix scan — use NUS service UUID instead of device name to find InclinoCore
2026-06-08 v0.0.16 — known devices, auto-connect on start, nickname persistence, icon fix, APK rename
2026-06-08 Fix BLE scan — remove withServices filter, match on MAC or NUS UUID in results
2026-06-08 Debug scan — show all BLE devices
2026-06-08 v0.0.30 — PIN pairing, known device auto-connect, MAC-based identification
2026-06-08 Fix string escape issues in PIN response JSON
    [main.cpp]
2026-06-08 Fix NVS — add custom partitions.csv with NVS partition
    [partitions.csv]
2026-06-08 Fix scan — check advName in addition to platformName
2026-06-08 Fix BLE scan — remove location from runtime permissions, update flutter_blue_plus
2026-06-08 Fix scan — use StreamSubscription, fixes infinite loop on Android
2026-06-11 v0.0.31 — 5s boot screen, 25% default brightness, new app icons
2026-06-11 Cleanup — remove stale files from satellite era and misplaced icons
2026-06-11 Update README — current features, PIN pairing, button usage, app features
2026-06-11 adding first 3d printing files for Core and tent brackest.
    [InclinoCar Core Case v26.1.0 - Box.stl, InclinoCar Core Case v26.1.0 - Clip.stl, InclinoCar Core Case v26.1.0 - Lid.stl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]
2026-06-11 Adding 3d print files for tent brackes.
    [InclinoCar - TT Brackets.3mf, InclinoCar Core Case v26.1.0 - Bracket_TT_Åreskutan2.0.stl, InclinoCar Core Case v26.1.0 - Powerbank_TT_Åreskutan2.0.stl]
2026-06-11 Revise README with published parts and settings
    Updated parts status and print settings for 3D prints.
2026-06-11 Add images to 3D Print README
    Added images to README for visual reference.
2026-06-11 Update README with correct bracket description
2026-06-11 v0.0.32 — BLE advertises as Core#MAC, nickname is display only
2026-06-15 Restructure — firmware/firmware-esp32c3 + firmware/firmware-m5stick, updated web installer
    [partitions.csv]
2026-06-15 Fix M5StickC Plus — correct board, M5.begin() init order, proper display calls
    [main.cpp]
2026-06-15 Fix M5Stick board ID — use m5stick-c (shared with Plus in PlatformIO)
2026-06-15 Fix M5Stick CI — use env name for build output path
2026-06-15 Switch M5Stick to M5Unified library — fixes blank screen and Serial
    [main.cpp]
2026-06-15 fw-m5stick-v0.0.1 — working display, BLE, IMU, side-mount orientation, tuned smoothing
2026-06-15 Fix M5Stick flash offsets — ESP32 bootloader at 0x1000 not 0x0
2026-06-15 Fix M5Stick web installer — add boot_app0.bin at 0xe000 required for ESP32
2026-06-15 fw-m5stick-v0.0.2 — improved screen layout, bigger text, no divider lines
2026-06-15 Update firmware section with device-specific badges
    Added specific firmware versions for ESP32-C3 and M5StickC Plus.
2026-06-15 Update README with M5StickCPlus note
    Added note about M5StickCPlus device and its drift issues.
2026-06-15 fw-m5stick-v0.0.3 — battery percentage and bar on display
2026-06-15 fw-m5stick-v0.0.4 — correct axes, median filter MF_SIZE=7, BtnA, battery display
    [main.cpp]
2026-06-15 fw-esp32c3-v0.0.33 — correct axis signs, median filter MF_SIZE=7
    [main.cpp]
2026-06-15 ci: esp32c3 fw-esp32c3-v0.0.33
2026-07-07 Add M5StickS3 hardware target — firmware, CI, manifest, README
2026-07-08 Web installer — add M5StickS3 target, per-chip bootloader offset, boot_app0 support
2026-07-21 fw-m5sticks3: tune median filter window for BMI270
    BMI270 is much less noisy than the MPU6050/MPU6886 used on the other
    targets, so a smaller MF_SIZE (7 -> 5) stays snappy without giving up
    the anti-spike benefit of a median filter.
    [main.cpp]
2026-07-23 3d-print: add M5S3 bracket and powerbank core case, update TT brackets
    Adds InclinoCar M5S3 v26.07.1 bracket and Core Case v26.1.1 (powerbank
    variant) STLs for the Taktältarna Åreskutan 2.0 mount, updates the TT
    Brackets 3MF.
    [InclinoCar - TT Brackets.3mf, InclinoCar Core Case v26.1.1 - Powerbank_TT_Åreskutan2.0.stl, InclinoCar M5S3 v26.07.1 - Bracket_TT_Åreskutan2.0.stl]
2026-07-27 Add boot-screen shortcut for reading the pairing PIN
    Adds a second button gesture on each target that redisplays the boot
    screen (nickname, MAC, PIN) for 10s without a reboot, since the PIN
    is otherwise only shown briefly at power-on. M5StickC Plus and
    M5StickS3 use a single BtnB press; ESP32-C3 (single-button hardware)
    uses a double-press within 350ms, which adds a matching ~350ms delay
    before the existing single-press brightness-cycle action fires.
    Extracted a shared drawBootScreen() on all three targets so setup()
    and the new button handler render from one source of truth.
    Tested on hardware on all three targets.
    [main.cpp]
2026-07-27 ci: fix race condition clobbering docs/bins on concurrent tag pushes
    All three firmware workflows committed binaries with `git push --force
    origin HEAD:main`. When multiple firmware tags are pushed together
    (common — e.g. tagging all targets for a release at once), the jobs
    run in parallel, each starting from the same base commit; whichever
    finishes last force-overwrote main with only its own change, silently
    discarding the other targets' binary/manifest commits.
    This is why the v26.07.2 web installer served v0.0.33 for ESP32-C3 and
    v0.0.4 for M5StickC Plus after tagging all three targets together —
    only m5sticks3 (last to finish) survived the force-push. The GitHub
    Releases themselves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
2026-07-27 ci: unshallow before rebase in commit-binaries retry loop
    The previous fix (446e9a4) replaced --force push with fetch+rebase+
    retry, but actions/checkout defaults to fetch-depth 1. Without full
    history, git rebase origin/main can't find the real merge base, so
    every retry failed immediately (confirmed: fw-esp32c3-v26.07.2 rebuild
    failed at the Commit binaries step within 13s). Unshallow the clone
    before rebasing so it has the commit graph it needs.
2026-07-27 ci: use reset --soft instead of rebase for concurrent-push retry
    The rebase-based retry (d4ba067) still failed the Commit binaries step
    even after unshallowing, since actions/checkout's shallow clone
    doesn't give rebase a reliable merge base to work from.
    git reset --soft origin/main sidesteps this entirely: it just moves
    HEAD to the latest main tip without touching the index/working tree,
    so the already-staged target-specific changes get recommitted cleanly
    on top regardless of clone depth. Validated locally by simulating a
    genuinely shallow clone (git rev-parse --is-shallow-repository: true)
    racing against a concurrent push — both changes land correctly with
    no clobbering.
    Co-Authored-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
2026-07-27 ci: fix reset --soft silently reverting other targets' files
    reset --soft (c2eb338) still had a bug: it leaves the index exactly as
    it was, which for a job's initial checkout means the index reflects
    main as it looked BEFORE this job started — for every path, not just
    this target's. When HEAD moves to the latest main tip but the index
    doesn't, git treats any file that changed elsewhere on main since
    checkout as a pending change to commit, silently reverting it back to
    the old content. This is exactly what happened: the m5stick job's
    retry reverted esp32c3's freshly-built firmware.bin and manifest back
    to v0.0.33, because its stale index still held the old blobs for those
    paths.
    Fixes it p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
2026-07-27 ci: auto-generate changelog in release notes
    Release bodies were static boilerplate (just flashing instructions),
    so every release needed its changelog pasted in by hand. Each workflow
    now finds the previous tag for its own target family, diffs the
    relevant source path (firmware/firmware-<target>/ or app/) between
    that tag and the current one, and writes commit subject lines into a
    "## What's Changed" section via body_path — no manual editing needed
    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
2026-07-27 Remove dead files: legacy pre-split web installer bins, superseded STL
    - docs/manifest.json + docs/bins/{bootloader,firmware,partitions}.bin:
    leftovers from before firmware split into 3 per-target manifests/bin
    folders. Unreferenced by docs/index.html, which only ever loads
    manifest-esp32c3/m5stick/m5sticks3.json.
    - 3d-print Core Case v26.1.0 Powerbank STL: superseded by v26.1.1.
    - MIGRATION-README.txt (untracked): one-time Claude Code bootstrap
    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
    [InclinoCar Core Case v26.1.0 - Powerbank_TT_Åreskutan2.0.stl]
2026-07-27 docs: fix README button table and 3d-print parts list
    README.md:
    - Button table incorrectly had M5StickC Plus using BtnB and M5StickS3
    using BtnA for brightness/calibrate; both targets actually use BtnA
    for that (confirmed against firmware source).
    - Document the v26.07.2 boot-screen shortcut (BtnB single-press on M5
    targets, double-press on ESP32-C3), previously undocumented.
    3d-print/README.md:
    - Fix "Publiched" typo.
    - Parts table only listed 2 generic rows and didn't reflect the
    bracket/powerbank/M5S3 variants actually in the folder.
2026-07-27 docs: fix physical button locations and remaining stale README content
    - BtnB is the top button on both M5 sticks (front-mounted was a guess,
    confirmed wrong against real hardware) — BtnA is front, power button
    is bottom and unrelated to app functions.
    - Intro line only mentioned ESP32-C3/MPU-6050, ignoring both M5Stick
    targets even though M5StickS3 is the recommended option.
    - Boot screen example showed a stale v0.0.4 placeholder.
    - Calibration section said "hold the button" without naming BtnA, now
    ambiguous since M5 targets have two buttons.
2026-07-27 docs: note BtnA's physical markings on each M5 device
    Labeled "M5" on the M5StickC Plus; unlabeled but blue on the M5StickS3.
2026-07-27 build: pin platform/lib versions for reproducible builds
    esp32c3 and m5stick left `platform = espressif32` unpinned (floats to
    latest), inconsistent with m5sticks3's pinned @6.12.0 and risking a
    surprise CI break on a future Espressif platform release. Pinned both
    to 7.0.1, the version already resolved and verified working locally.
    m5sticks3's M5Unified/M5PM1 are pulled from raw GitHub URLs (needed
    since neither is in the PlatformIO registry in a form that supports
    the S3 well) with no version pin at all — every cold-cache build grabs
    whatever's on their default branch right now. Pinned to the exact tags
    (0.2.17, 1.0.7) that were actually fetched and verified building today.
    All three ta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
2026-07-28 docs: correct M5StickS3 USB dev-workflow issue — freeze, not reboot
    Diagnosed with the user via live testing on hardware: connecting to a
    PC with a serial port open (e.g. VS Code/PlatformIO) but no monitor
    actively reading it causes the device to freeze in place. Confirmed
    this is NOT a reboot — no boot screen replay — contradicting the
    previously documented "boot-loops" / DTR-RTS chip-reset explanation,
    which would produce a visible restart. Opening a serial monitor
    un-freezes it immediately; closing it freezes it again, consistent
    with a full/blocked USB-CDC TX buffer, though the already-applied
    Serial.setTxTimeoutMs(0) doesn't fully prevent it — exact mechanism
    still not fully con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
2026-07-30 3d-print: update M5S3 bracket for Taktältarna Åreskutan 2.0
    [InclinoCar M5S3 v26.07.1 - Bracket_TT_Åreskutan2.0.stl]
